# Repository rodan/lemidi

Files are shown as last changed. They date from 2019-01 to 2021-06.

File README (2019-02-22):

 an interface based on a MSP430F5510 that allows the use of usb 1.x-2.0 joysticks 
 with retro gaming PCs that have a game port.

 source:       https://github.com/rodan/lemidi
               https://cadlab.io/projects/lemidi
 author:       Petre Rodan <2b4eda@subdimension.ro>
 license:      GNU GPLv3
 prototype pictures available here: https://photos.app.goo.gl/fXdDBng4dvEepq8V7

 tested and supported joysticks:

    Logitech Extreme 3D Pro
        ID 046d:c215 Logitech, Inc. Extreme 3D Pro

    Logitech Attack 3
        ID 046d:c214 Logitech, Inc. ATK3 (Attack III Joystick)

    Genius F-23
        ID 0458:1004 KYE Systems Corp. (Mouse Systems) Flight2000 F-23 Joystick

 tested game ports:

    Sound Blaster Live! CT-4810
    (any game port should be supported)

 the interface has an inbuilt overcurrent protection that activates if the 
 connected peripheral sinks over 200mA on the 5V bus. once the peripheral is 
 removed service will resume.

LED statuses:

green led - ON  - if peripheral is supported and succesfully initialized
           OFF  - if supported peripheral is disconnected
           OFF  - if overcurrent condition is triggered

red led -   ON  - if init failed or during overcurrent condition
           OFF  - end of init
           OFF  - end of overcurrent condition
   short blink  - during device power-on

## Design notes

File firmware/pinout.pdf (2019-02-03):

PORT1

pin | P | N | name | SEL | OUT | DIR | description
1.0 | 1 | 0 | USB_GPX | 0 | 0 | 0 general interrupt from USB IC
1.1 | 1 | 1 | USB_INT | 0 | 0 | 0 USB protocol interrupt
1.2 | 1 | 2 | | 0 | 0 | 0
1.3 | 1 | 3 | | 0 | 0 | 0
1.4 | 1 | 4 | B4_EN | 0 | 0 | 1 activate button #4, active high
1.5 | 1 | 5 | B3_EN | 0 | 0 | 1 activate button #3, active high
1.6 | 1 | 6 | B2_EN | 0 | 0 | 1 activate button #2, active high
1.7 | 1 | 7 | B1_EN | 0 | 0 | 1 activate button #1, active high
init | 0x0 0x0 0xF0

pin | P | N | name | SEL | OUT | DIR | description
2.0 | 2 | 0 | | 0 | 0 | 0
2.1 | 2 | 1 | | 0 | 0 | 0
2.2 | 2 | 2 | | 0 | 0 | 0
2.3 | 2 | 3 | | 0 | 0 | 0
2.4 | 2 | 4 | | 0 | 0 | 0
2.5 | 2 | 5 | | 0 | 0 | 0
2.6 | 2 | 6 | | 0 | 0 | 0
2.7 | 2 | 7 | | 0 | 0 | 0
init | 0x0 0x0 0x0

pin | P | N | name | SEL | OUT | DIR | description
3.0 | 3 | 0 | | 0 | 0 | 0
3.1 | 3 | 1 | | 0 | 0 | 0
3.2 | 3 | 2 | | 0 | 0 | 0
3.3 | 3 | 3 | | 0 | 0 | 0
3.4 | 3 | 4 | | 0 | 0 | 0
init | 0x0 0x0 0x0

pin | P | N | name | SEL | OUT | DIR | description
4.0 | 4 | 0 | CS_USB | 0 | 1 | 1 chip select, USB IC, active low
4.1 | 4 | 1 | MOSI | 1 | 0 | 0 SPI
4.2 | 4 | 2 | MISO | 1 | 0 | 0 SPI
4.3 | 4 | 3 | SCLK | 1 | 0 | 0 SPI
4.4 | 4 | 4 | TX | 1 | 0 | 0 UART, debug port
4.5 | 4 | 5 | RX | 1 | 0 | 0 UART, debug port
4.6 | 4 | 6 | CS_J2 | 0 | 1 | 1 chip select, joystick #2, active low
4.7 | 4 | 7 | CS_J1 | 0 | 1 | 1 chip select, joystick #1, active low
init | 0x3E 0xC1 0xC1

pin | P | N | name | SEL | OUT | DIR | description
5.0 | 5 | 0 | | 0 | 0 | 0
5.1 | 5 | 1 | | 0 | 0 | 0
5.2 | 5 | 2 | HF XO | 1 | 0 | 0 crystal mode
5.3 | 5 | 3 | HF XI | 1 | 0 | 0 crystal mode
5.4 | 5 | 4 | | 0 | 0 | 0
5.5 | 5 | 5 | | 0 | 0 | 0
init | 0xC 0x0 0x0

pin | P | N | name | SEL | OUT | DIR | description
6.0 | 6 | 0 | | 0 | 0 | 0
6.1 | 6 | 1 | USB_RST | 0 | 0 | 1 reset the USB IC, active low
6.2 | 6 | 2 | | 0 | 0 | 0
6.3 | 6 | 3 | | 0 | 0 | 0
6.4 | 6 | 4 | | 0 | 0 | 0
6.5 | 6 | 5 | | 0 | 0 | 0
6.6 | 6 | 6 | | 0 | 0 | 0
6.7 | 6 | 7 | | 0 | 0 | 0
init | 0x0 0x0 0x2

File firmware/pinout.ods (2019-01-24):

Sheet: PORT1
 | pin | P | N | name | SEL | OUT | DIR | REN | description
 | 1.0 | 1 | 0 | USB_GPX | 0 | 1 | 0 | 1 | general interrupt from USB IC
 | 1.1 | 1 | 1 | USB_INT | 0 | 1 | 0 | 1 | USB protocol interrupt
 | 1.2 | 1 | 2 | - | 0 | 0 | 1 | 0 | unused
 | 1.3 | 1 | 3 | - | 0 | 0 | 1 | 0 | unused
 | 1.4 | 1 | 4 | B4_EN | 0 | 0 | 1 | 0 | activate button #4, active high
 | 1.5 | 1 | 5 | B3_EN | 0 | 0 | 1 | 0 | activate button #3, active high
 | 1.6 | 1 | 6 | B2_EN | 0 | 0 | 1 | 0 | activate button #2, active high
 | 1.7 | 1 | 7 | B1_EN | 0 | 0 | 1 | 0 | activate button #1, active high
init |  |  |  |  | 0x0 | 0x3 | 0xFC | 0x3

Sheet: PORT2
 | pin | P | N | name | SEL | OUT | DIR | REN | description
 | 2.0 | 2 | 0 |  | 0 | 0 | 1 | 0 | unused
 | 2.1 | 2 | 1 |  | 0 | 0 | 1 | 0 | NC
 | 2.2 | 2 | 2 |  | 0 | 0 | 1 | 0 | NC
 | 2.3 | 2 | 3 |  | 0 | 0 | 1 | 0 | NC
 | 2.4 | 2 | 4 |  | 0 | 0 | 1 | 0 | NC
 | 2.5 | 2 | 5 |  | 0 | 0 | 1 | 0 | NC
 | 2.6 | 2 | 6 |  | 0 | 0 | 1 | 0 | NC
 | 2.7 | 2 | 7 |  | 0 | 0 | 1 | 0 | NC
init |  |  |  |  | 0x0 | 0x0 | 0xFF | 0x0
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

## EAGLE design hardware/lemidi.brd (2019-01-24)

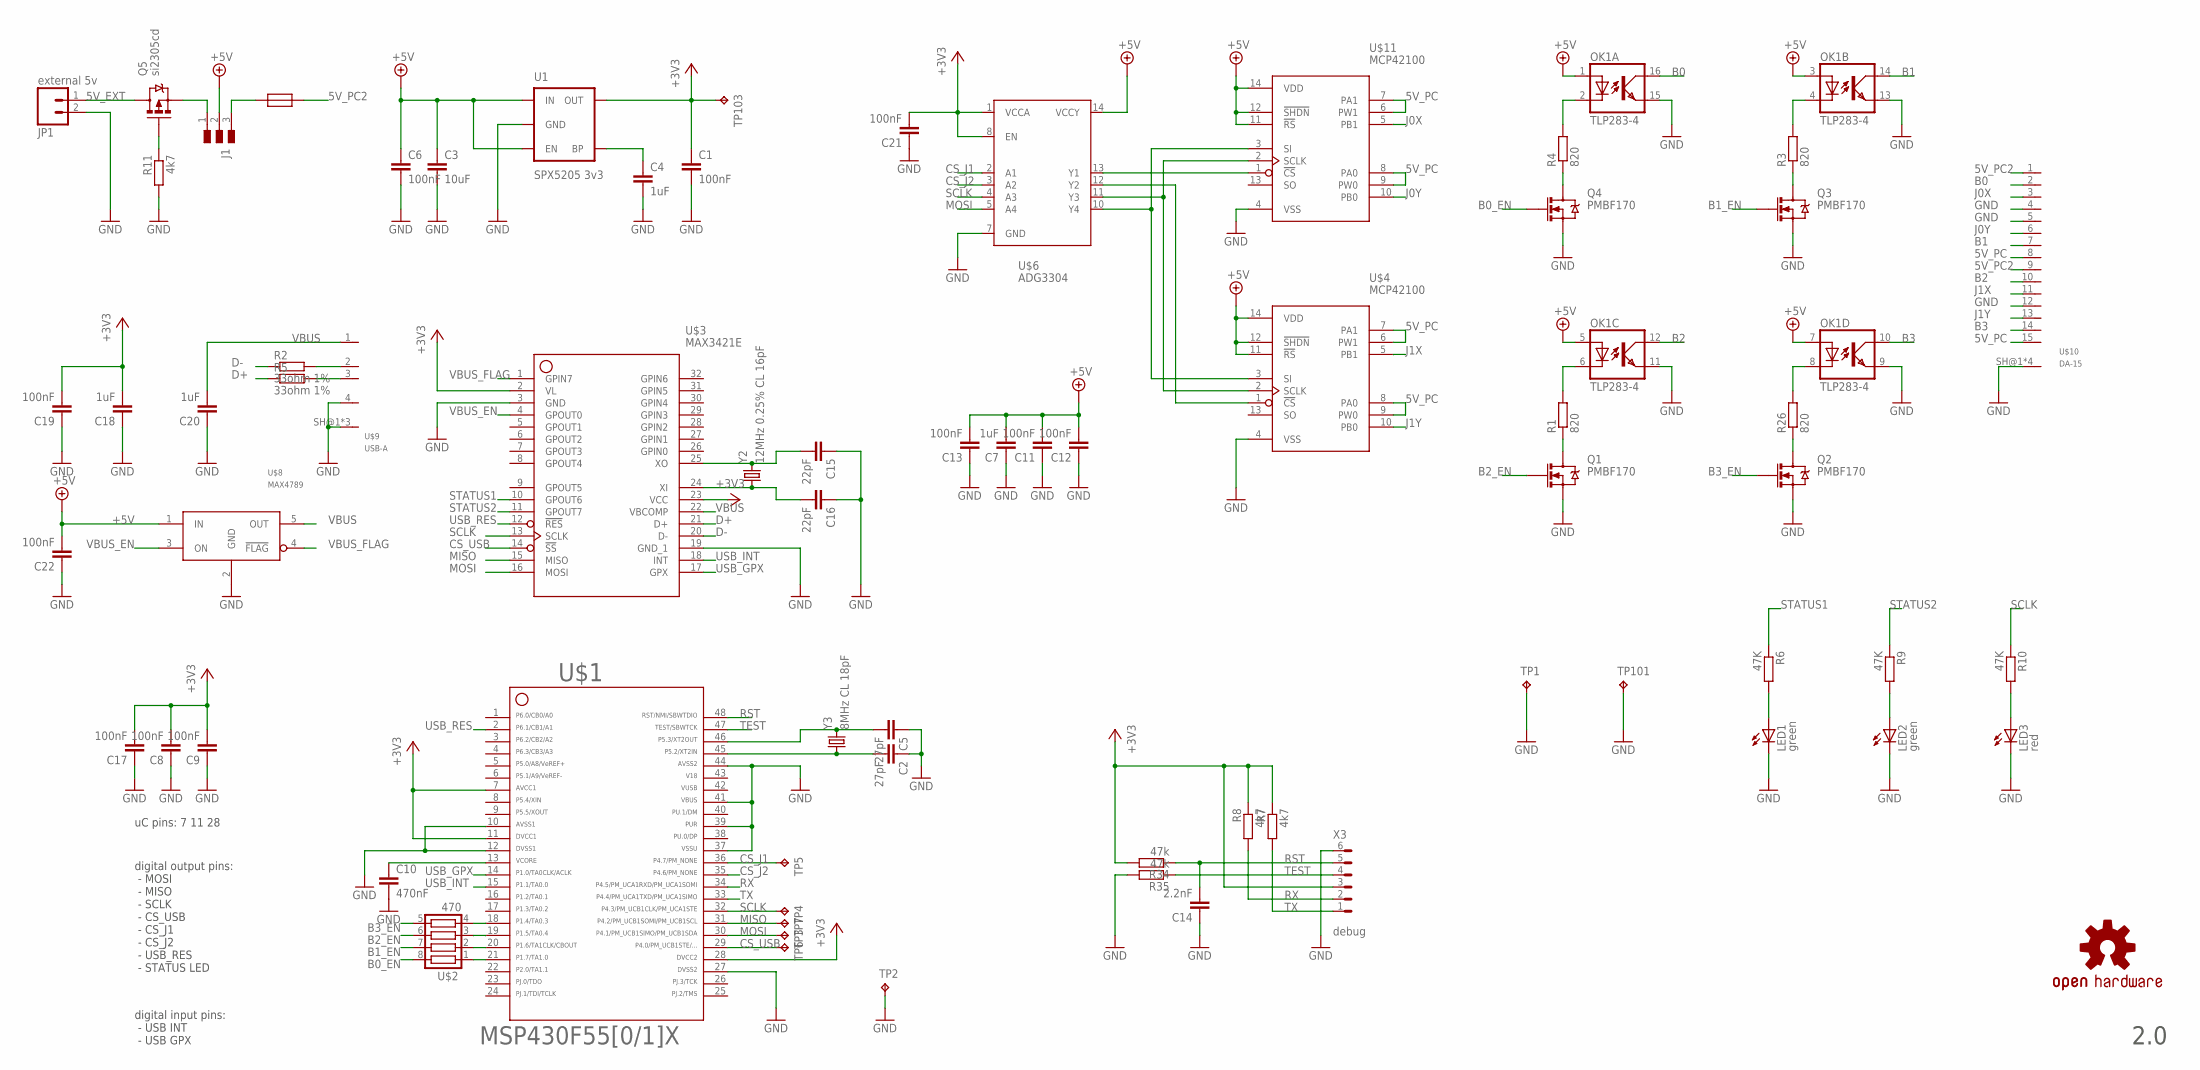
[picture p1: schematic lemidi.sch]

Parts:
C1, C6, C8, C9, C11, C12, C13, C17, C19, C21, C22: 100nF; C0805
C2, C5: 27pF; C0805
C3: 10uF; C0805
C4, C7, C18, C20: 1uF; C0805
C10: 470nF; C0805
C14: 2.2nF; C0805
C15, C16: 22pF; C0805
J1: SJ_3P
JP1: external 5v; 1X02
LED1, LED2: green; CHIPLED_0805
LED3: red; CHIPLED_0805
OK1: TLP283-4; MINI-FLAT-16
Q1, Q2, Q3, Q4: PMBF170; SOT23-3
Q5: si2305cd; SOT23-3_POWER
R1, R3, R4, R26: 820; R0805W
R2, R5: 33ohm 1%; R0805W
R6, R9, R10: 47K; R0805W
R7, R8, R11: 4k7; R0805W
R34, R35: 47k; R0805W
TP1, TP2, TP3, TP4, TP5, TP6, TP7, TP101, TP103: TPTP12R; TP12R
U1: SPX5205 3v3; SOT23-5
U$1: MSP430F5510; PT48
U$2: 470; YC164
U$3: MAX3421E; TQFP32
U$4, U$11: MCP42100; SO-14
U$6: ADG3304; TSSOP14
U$7: OSHW-LOGOM; OSHW-LOGO-M
U$8: MAX4789; SOT23-5
U$9: USB-A; UBA-4R-D14T-4D
U$10: DA-15; ADAM_TECH_D-SUB_15
U$12: RESETTABLE_1210; 1210
X3: debug; 0530480610
Y2: 12MHz 0.25% CL 16pF; CRYSTAL-SMD-11.4X4.35
Y3: 8MHz CL 18pF; CRYSTAL-SMD-11.4X4.35

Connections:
5V_EXT: JP1.1, Q5.3 (D)
5V_PC: U$4.6 (PW1), U$4.7 (PA1), U$4.8 (PA0), U$4.9 (PW0), U$10.8, U$10.15, U$11.6 (PW1), U$11.7 (PA1), U$11.8 (PA0), U$11.9 (PW0)
5V_PC2: U$10.1, U$10.9, U$12.P$2
12MHX_XI: C16.2, U$3.24 (XI), Y2.1
12MHZ_XO: C15.2, U$3.25 (XO), Y2.2
42: U$1.42
43: U$1.43
+3V3: C1.1, C8.2, C9.2, C17.2, C18.2, C19.2, C21.2, R7.1, R8.1, R34.2, TP103.TP, U1.5 (OUT), U$1.7, U$1.11, U$1.28, U$3.2 (VL), U$3.23 (VCC), U$6.1 (VCCA), U$6.8 (EN), X3.3 (4)
+5V: C3.1, C6.1, C7.2, C11.2, C12.2, C13.2, C22.2, J1.2, OK1.1 (A), OK1.3 (A), OK1.5 (A), OK1.7 (A), U1.1 (IN), U1.3 (EN), U$4.11 (!RS), U$4.12 (!SHDN), U$4.14 (VDD), U$6.14 (VCCY), U$8.1 (IN), U$11.11 (!RS), U$11.12 (!SHDN), U$11.14 (VDD)
B0: OK1.16 (COL), U$10.2
B0_EN: Q4.1 (G), U$2.8
B1: OK1.14 (COL), U$10.7
B1_EN: Q3.1 (G), U$2.7
B2: OK1.12 (COL), U$10.10
B2_EN: Q1.1 (G), U$2.6
B3: OK1.10 (COL), U$10.14
B3_EN: Q2.1 (G), U$2.5
CS_J1: TP5.TP, U$1.36, U$6.2 (A1)
CS_J2: U$1.35, U$6.3 (A2)
CS_USB: TP6.TP, U$1.29, U$3.14 (!SS)
D+: R5.1, U$3.21 (D+)
D-: R2.1, U$3.20 (D-)
GND: C1.2, C2.1, C3.2, C4.2, C5.1, C6.2, C7.1, C8.1, C9.1, C10.2, C11.1, C12.1, C13.1, C14.1, C15.1, C16.1, C17.1, C18.1, C19.1, C20.1, C21.1, C22.1, JP1.2, LED1.C, LED2.C, LED3.C, OK1.9 (EMIT), OK1.11 (EMIT), OK1.13 (EMIT), OK1.15 (EMIT), Q1.2 (S), Q2.2 (S), Q3.2 (S), Q4.2 (S), R11.2, R35.2, TP1.TP, TP2.TP, TP101.TP, U1.2 (GND), U$1.10, U$1.12, U$1.27, U$1.37, U$1.39, U$1.41, U$1.44, U$3.3 (GND), U$3.19 (GND_1), U$4.4 (VSS), U$6.7 (GND), U$8.2 (GND), U$9.4, U$9.SH@1 (SH), U$9.SH@2 (SH), U$9.SH@3 (SH), U$10.4, U$10.5, U$10.12, U$10.SH@1 (SHIELD), U$10.SH@2 (SHIELD), U$10.SH@3 (SHIELD), U$10.SH@4 (SHIELD), U$11.4 (VSS), X3.6 (1)
HIGH_CS1: U$6.13 (Y1), U$11.1 (!CS)
HIGH_CS2: U$4.1 (!CS), U$6.12 (Y2)
HIGH_MOSI: U$4.3 (SI), U$6.10 (Y4), U$11.3 (SI)
HIGH_SCLK: U$4.2 (SCLK), U$6.11 (Y3), U$11.2 (SCLK)
J0X: U$10.3, U$11.5 (PB1)
J0Y: U$10.6, U$11.10 (PB0)
J1X: U$4.5 (PB1), U$10.11
J1Y: U$4.10 (PB0), U$10.13
MISO: TP7.TP, U$1.31, U$3.15 (MISO)
MOSI: TP3.TP, U$1.30, U$3.16 (MOSI), U$6.5 (A4)
unnamed: LED1.A, R6.2
unnamed: C4.1, U1.4 (BP)
unnamed: U$1.18, U$2.4
unnamed: LED2.A, R9.2
unnamed: Q1.3 (D), R1.1
unnamed: C10.1, U$1.13
unnamed: OK1.6 (C), R1.2
unnamed: U$1.19, U$2.3
unnamed: OK1.8 (C), R26.2
unnamed: J1.3, U$12.P$1
unnamed: LED3.A, R10.2
unnamed: Q3.3 (D), R3.1
unnamed: OK1.4 (C), R3.2
unnamed: Q4.3 (D), R4.1
unnamed: OK1.2 (C), R4.2
unnamed: R5.2, U$9.3
unnamed: R2.2, U$9.2
unnamed: U$1.20, U$2.2
unnamed: U$1.21, U$2.1
unnamed: Q2.3 (D), R26.1
unnamed: J1.1, Q5.2 (S)
unnamed: Q5.1 (G), R11.1
RST: C14.2, R34.1, U$1.48, X3.5 (2)
RX: R8.2, U$1.34, X3.2 (5)
SCLK: R10.1, TP4.TP, U$1.32, U$3.13 (SCLK), U$6.4 (A3)
STATUS1: R6.1, U$3.10 (GPOUT6)
STATUS2: R9.1, U$3.11 (GPOUT7)
TEST: R35.1, U$1.47, X3.4 (3)
TX: R7.2, U$1.33, X3.1 (6)
USB_GPX: U$1.14, U$3.17 (GPX)
USB_INT: U$1.15, U$3.18 (INT)
USB_RES: U$1.2, U$3.12 (!RES)
VBUS: C20.2, U$3.22 (VBCOMP), U$8.5 (OUT), U$9.1
VBUS_EN: U$3.4 (GPOUT0), U$8.3 (ON)
VBUS_FLAG: U$3.1 (GPIN7), U$8.4 (!FLAG)
XT2IN: C2.2, U$1.45, Y3.1
XT2OUT: C5.2, U$1.46, Y3.2

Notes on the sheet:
2.0
uC pins: 7 11 28
digital output pins: - MOSI - MISO - SCLK - CS_USB - CS_J1 - CS_J2 - USB_RES - STATUS LED
digital input pins: - USB INT - USB GPX

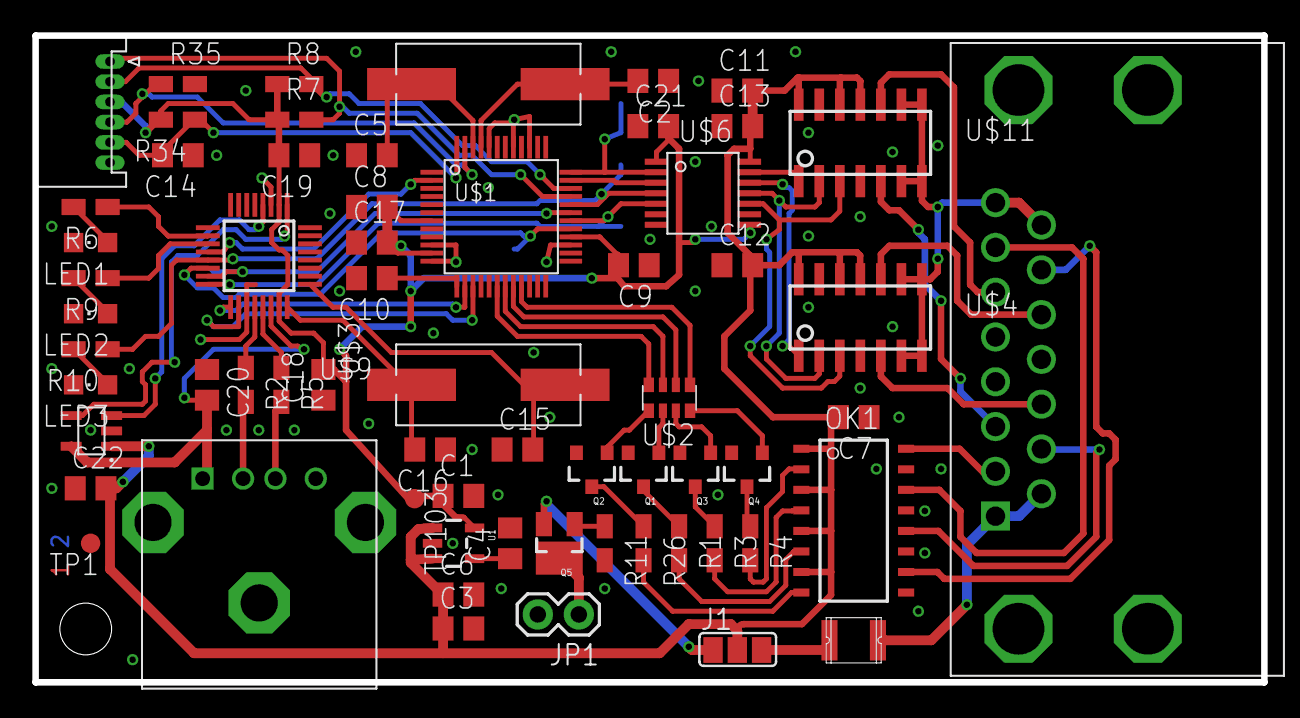
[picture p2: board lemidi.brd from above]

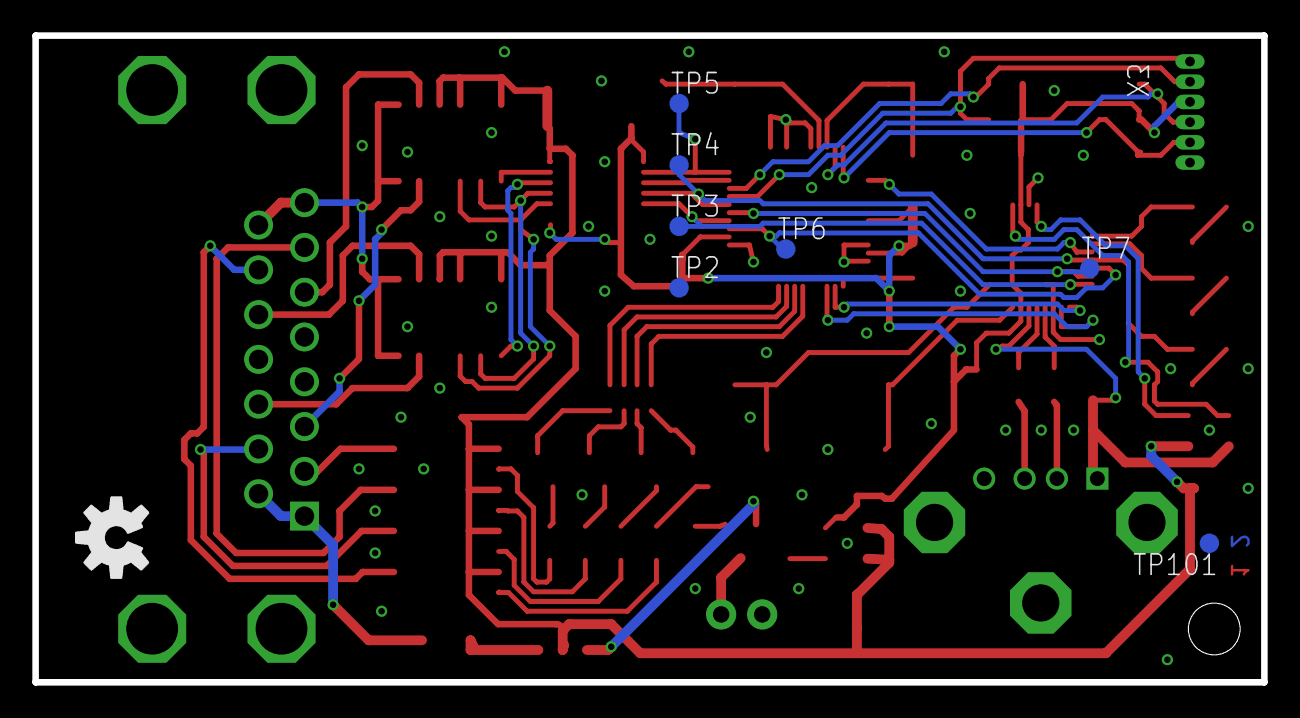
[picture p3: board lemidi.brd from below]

Board: 2 copper layers, 76.0 x 40.0 mm, 71 parts (8 on the bottom side), 68 nets.

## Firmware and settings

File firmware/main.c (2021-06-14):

//  USB to MIDI interface based on a MSP430F5510 uC
//
//  author:          Petre Rodan <2b4eda@subdimension.ro>
//  available from:  https://github.com/rodan/
//  license:         GNU GPLv3

#include <stdio.h>
#include <string.h>

#include "proj.h"
#include "drivers/sys_messagebus.h"
#include "drivers/timer_a0.h"
#include "drivers/uart0.h"
#include "drivers/spi.h"
#include "drivers/mcp42xxx.h"
#include "drivers/max3421.h"
#include "qa.h"

#if (CONFIG_LOG_LEVEL > LOG_LEVEL_NONE)
static void parse_UI(const uint16_t msg)
{
    parse_user_input();
    uart0_set_eol();
}
#endif

int main(void)
{
    main_init();

    timer_a0_init();
    // start the millis counter
    timer_a0_delay_noblk_ccr3(125);

#if (CONFIG_LOG_LEVEL > LOG_LEVEL_NONE)
    uart0_init();
    sys_messagebus_register(&parse_UI, SYS_MSG_UART0_RX);
#endif

    spi_init();
    spi_fast_mode();

    // stay a while and listen
    while (millis() < 1000) {}

    MAX3421_init();

    // main loop
    while (1) {
        __bis_SR_register(LPM0_bits + GIE);
#ifdef USE_WATCHDOG
        // reset watchdog counter
        WDTCTL = (WDTCTL & 0xff) | WDTPW | WDTCNTCL;
#endif
        check_events();
        check_events();
        check_events();
    }
}

void main_init(void)
{
    // watchdog triggers after 1 second when not cleared
#ifdef USE_WATCHDOG
    // 2^23/8000000Hz ~= 1sec
    WDTCTL = WDTPW + WDTIS__8192K + WDTSSEL__SMCLK + WDTCNTCL;
#else
    WDTCTL = WDTPW + WDTHOLD;
#endif

    // ports - consult the pinout file
    P1SEL = 0;
    P1OUT = 0x0;
    P1DIR = 0xfc;
    P1REN = 0x0;

    // IRQ triggers on a high to low transition
    P1IES |= INT_TRIG | GPX_TRIG;
    // Reset IRQ flags
    P1IFG &= ~(INT_TRIG + GPX_TRIG);
    // Enable interrupts
    P1IE |= INT_TRIG | GPX_TRIG;

    P2SEL = 0;
    P2OUT = 0;
    P2DIR = 0xff;
    P2REN = 0;

    P3SEL = 0;
    P3OUT = 0;
    P3DIR = 0x1f;
    P3REN = 0;

    PMAPPWD = 0x02D52;
    // set up port mappings
    P4MAP4 = PM_UCA0TXD;
    P4MAP5 = PM_UCA0RXD;
    PMAPPWD = 0;

    P4SEL = 0x3e;
    P4OUT = 0xc1;
    P4DIR = 0xc1;
    P4REN = 0;

    P5SEL = 0xc;
    P5OUT = 0;
    P5DIR = 0x33;

    P6SEL = 0;
    P6OUT = 0;
    P6DIR = 0xff;
    P6REN = 0x0;

    PJOUT = 0x00;
    PJDIR = 0xFF;

    // disable VUSB LDO and SLDO
    USBKEYPID = 0x9628;
    USBPWRCTL &= ~(SLDOEN + VUSBEN);
    USBKEYPID = 0x9600;

    // crystals
#ifdef USE_XT1
    // enable external LF crystal if one is present
    P5SEL |= BIT4+BIT5;
    UCSCTL6 &= ~XT1OFF;
    // Loop until XT1 stabilizes
    do {
        UCSCTL7 &= ~XT1LFOFFG;                 // clear XT1 fault flags
        SFRIFG1 &= ~OFIFG;                     // clear fault flags
    } while ( UCSCTL7 & XT1LFOFFG );           // test XT1 fault flag
    UCSCTL6 &= ~(XT1DRIVE0 + XT1DRIVE1);
    UCSCTL4 |= SELA__XT1CLK;
#else
    // use internal 32768 Hz oscillator
    UCSCTL4 |= SELA__REFOCLK;
#endif

#ifdef USE_XT2
    // enable HF crystal if one is present
    P5SEL |= BIT2+BIT3;                       // port select XT2
    UCSCTL6 &= ~XT2OFF;                       // set XT2 On
    // Loop until XT2 & DCO stabilizes
    do {
        UCSCTL7 &= ~(XT2OFFG + DCOFFG);        // clear XT2, DCO fault flags
        SFRIFG1 &= ~OFIFG;                     // clear fault flags
    } while ( UCSCTL7 & (XT2OFFG + DCOFFG) );  // test fault flags

    UCSCTL6 &= ~XT2DRIVE1;                      // Decrease XT2 drive
    UCSCTL4 |= SELS__XT2CLK + SELM__XT2CLK;
#endif

}

void check_events(void)
{
    struct sys_messagebus *p = sys_messagebus_getp();
    uint16_t msg = SYS_MSG_NULL;

    // drivers/timer0a
    if (timer_a0_get_event()) {
        msg |= timer_a0_get_event();
        timer_a0_rst_event();
    }

    // drivers/uart0
    if (uart0_get_event() & UART0_EV_RX) {
        msg |= SYS_MSG_UART0_RX;
        uart0_rst_event();
    }

    // USB INT event
    if (get_ifg_int_event()) {
        msg |= SYS_MSG_P1IFG_INT;
        rst_ifg_int_event();
    }

    // USB GPX event
    if (get_ifg_gpx_event()) {
        msg |= SYS_MSG_P1IFG_GPX;
        rst_ifg_gpx_event();
    }

    while (p) {
        // notify listener if he registered for any of these messages
        if (msg & p->listens) {
            p->fn(msg);
        }
        p = p->next;
    }
}

void noInterrupts(void)
{
    P1IFG &= ~(INT_TRIG | GPX_TRIG);
    P1IE &= ~(INT_TRIG | GPX_TRIG);
}

void interrupts(void)
{
    P1IFG &= ~(INT_TRIG | GPX_TRIG);
    P1IE |= (INT_TRIG | GPX_TRIG);
}

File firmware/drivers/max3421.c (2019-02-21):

// C library for the MAX3421E USB peripheral/host controller IC
//   author:          Petre Rodan <2b4eda@subdimension.ro>
//   available from:  https://github.com/rodan/
//   license:         GNU GPLv3

// USB library stol^W borrowed from https://github.com/felis/UHS30
/* Copyright (C) 2015-2016 Andrew J. Kroll
   and
Copyright (C) 2011 Circuits At Home, LTD. All rights reserved.

This software may be distributed and modified under the terms of the GNU
General Public License version 2 (GPL2) as published by the Free Software
Foundation and appearing in the file GPL2.TXT included in the packaging of
this file. Please note that GPL2 Section 2[b] requires that all works based
on this software must also be made publicly available under the terms of
the GPL2 ("Copyleft").

Contact information
-------------------

Circuits At Home, LTD
Web      :  http://www.circuitsathome.com
e-mail   :  support@circuitsathome.com
*/

#include <inttypes.h>
#include <string.h>
#include "max3421.h"
#include "spi.h"
#include "drivers/sys_messagebus.h"
#include "drivers/timer_a0.h"
#include "drivers/mcp42xxx.h"
#include "HIDParser.h"
#include "proj.h"
#include "usb_spec.h"

#if (CONFIG_LOG_LEVEL > LOG_LEVEL_NONE)
#include "drivers/uart0.h"
#include "drivers/helper.h"
char itoa_buf[18];
#endif

volatile uint8_t vbusState;
volatile uint16_t sof_countdown;
volatile uint8_t bus_event;

volatile uint8_t usb_error;
volatile uint8_t usb_task_state;
volatile uint8_t usb_host_low_speed;    // if 0 it's HIGH speed, 1 is LOW speed

volatile uint8_t ifg_int_last_event;
volatile uint8_t ifg_gpx_last_event;

uint16_t HID_bInterval;         // bInterval saved from the Endpoint Descriptor (poll time in ms)
uint32_t qNextPollTime;         // when the next poll will take place (ms based on millis)

struct UHS_Device thePool[UHS_HOST_MAX_INTERFACE_DRIVERS];
// Endpoint data structure used during enumeration for uninitialized device
struct UHS_EpInfo dev0ep;
// HID-related epInfo
struct UHS_EpInfo hid_epInfo;
struct ENUMERATION_INFO ei;
HID_ReportInfo_t HID_ri;

void VBUS_changed(void)
{
    // modify USB task state because Vbus changed or unknown
    // start with low speed
    uint8_t low_speed = 0;
    uint8_t iostate;

#if (CONFIG_LOG_LEVEL > LOG_LEVEL_INFO)
    uart0_print("state ");
    uart0_print(_utoh(itoa_buf, usb_task_state));
#endif
    switch (vbusState) {
    case LSHOST:               // ? Low speed
        low_speed = 1;
        // Intentional fall-through
    case FSHOST:               // ? Full speed
        // Start device initialization if we are not initializing
        // Resets to the device cause an IRQ
        // usb_task_state == UHS_USB_HOST_STATE_RESET_NOT_COMPLETE;
        //if((usb_task_state & UHS_USB_HOST_STATE_MASK) != UHS_USB_HOST_STATE_DETACHED) {
        if (!(bus_event & doingreset)) {
            if (usb_task_state == UHS_USB_HOST_STATE_RESET_NOT_COMPLETE) {
                usb_task_state = UHS_USB_HOST_STATE_WAIT_BUS_READY;
            } else if (usb_task_state != UHS_USB_HOST_STATE_WAIT_BUS_READY) {
                usb_task_state = UHS_USB_HOST_STATE_DEBOUNCE;
            }
        }
        sof_countdown = 0;
        break;
    case SE1:                  //illegal state
        sof_countdown = 0;
        bus_event &= ~doingreset;
        usb_task_state = UHS_USB_HOST_STATE_ILLEGAL;
        break;
    case SE0:                  //disconnected
    default:
        sof_countdown = 0;
        bus_event &= ~doingreset;
        usb_task_state = UHS_USB_HOST_STATE_IDLE;

        // only one device can be connected and it's currently not
        FreeAddress(1);
        // turn green led off
        iostate = regRd(rIOPINS2) & ~bmGPOUT7;
        regWr(rIOPINS2, iostate);
        break;
    }
    usb_host_low_speed = low_speed;
#if (CONFIG_LOG_LEVEL > LOG_LEVEL_INFO)
    uart0_print("-> ");
    uart0_print(_utoh(itoa_buf, usb_task_state));
    uart0_print("\r\n");
#endif
    return;
}

// state machine
void MAX3421_sm(void)
{
    uint8_t x;
    uint8_t iostate;
    if (bus_event & condet) {
        VBUS_changed();
        bus_event &= ~condet;
    }

    switch (usb_task_state) {
    case UHS_USB_HOST_STATE_INITIALIZE:
        busprobe();
        VBUS_changed();
        break;
    case UHS_USB_HOST_STATE_DEBOUNCE:
        sof_countdown = UHS_HOST_DEBOUNCE_DELAY_MS;
        usb_task_state = UHS_USB_HOST_STATE_DEBOUNCE_NOT_COMPLETE;
        break;
    case UHS_USB_HOST_STATE_DEBOUNCE_NOT_COMPLETE:
        if (!sof_countdown) {
            usb_task_state = UHS_USB_HOST_STATE_RESET_DEVICE;
        }
        break;
    case UHS_USB_HOST_STATE_RESET_DEVICE:
#if (CONFIG_LOG_LEVEL > LOG_LEVEL_WARNING)
        uart0_print("sm rst dev\r\n");
#endif
        bus_event |= busevent;
        usb_task_state = UHS_USB_HOST_STATE_RESET_NOT_COMPLETE;
        regWr(rHIRQ, bmBUSEVENTIRQ);    // see data sheet.
        regWr(rHCTL, bmBUSRST); // issue bus reset
        break;
    case UHS_USB_HOST_STATE_RESET_NOT_COMPLETE:
        if (!busevent)
            usb_task_state = UHS_USB_HOST_STATE_WAIT_BUS_READY;
        break;
    case UHS_USB_HOST_STATE_WAIT_BUS_READY:
        usb_task_state = UHS_USB_HOST_STATE_CONFIGURING;
        break;                  // don't fall through

    case UHS_USB_HOST_STATE_CONFIGURING:
        usb_task_state = UHS_USB_HOST_STATE_CHECK;
#if (CONFIG_LOG_LEVEL > LOG_LEVEL_WARNING)
        uart0_print("sm conf\r\n");
#endif
        x = configure(0, 1, usb_host_low_speed);
        usb_error = x;
        if (usb_task_state == UHS_USB_HOST_STATE_CHECK) {
            if (x) {
#if (CONFIG_LOG_LEVEL > LOG_LEVEL_NONE)
                uart0_print("sm err ");
                uart0_print(_utoh(itoa_buf, x));
#endif
                if (x == UHS_HOST_ERROR_JERR) {
                    usb_task_state = UHS_USB_HOST_STATE_IDLE;
                } else if (x != UHS_HOST_ERROR_DEVICE_INIT_INCOMPLETE) {
                    usb_error = x;
                    usb_task_state = UHS_USB_HOST_STATE_ERROR;
                }
            } else {
                usb_task_state = UHS_USB_HOST_STATE_CONFIGURING_DONE;
            }
        }
        break;
    case UHS_USB_HOST_STATE_CHECK:
        break;
    case UHS_USB_HOST_STATE_CONFIGURING_DONE:
        usb_task_state = UHS_USB_HOST_STATE_RUNNING;

        // assert led2 (green)
        iostate = regRd(rIOPINS2) | bmGPOUT7;
        regWr(rIOPINS2, iostate);
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

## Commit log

2018-12-31 happy new year
    [lemidi.brd, lemidi.sch]
2019-01-02 ERC pass
    [lemidi.brd, lemidi.sch]
2019-01-02 DRC pass
    [lemidi.brd]
2019-01-02 1st cleanup
    [lemidi.brd, lemidi.sch]
2019-01-02 2nd cleanup
    [lemidi.brd, lemidi.sch]
2019-01-02 3rd cleanup
    [lemidi.brd, lemidi.sch]
2019-01-02 split 5v inputs from the midi connector, add fuse, add reverse polarity protection for external 5v input
    [lemidi.brd, lemidi.sch]
2019-01-05 switch to MCP42xxx digital pot
    [lemidi.brd, lemidi.sch]
2019-01-24 rev 2
    [lemidi.brd, lemidi.sch, pinout.ods]
2019-01-26 assembly done
2019-01-30 interrupt handlers
2019-02-03 added cpp code, none working
    [pinout.ods]
2019-02-07 base timer0 on SMCLK
2019-02-07 switch to 115200 baud
2019-02-07 ignore GERBER files
2019-02-09 debug print cleanu
2019-02-11 replace CONFIG_PRINTF with CONFIG_LOG_LEVEL
    [max3421.c, timer_a0.h]
2019-02-16 add traces
2019-02-17 switch to 2MHz SPI bus

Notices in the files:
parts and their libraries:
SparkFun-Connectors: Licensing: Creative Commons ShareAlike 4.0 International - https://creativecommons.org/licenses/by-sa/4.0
